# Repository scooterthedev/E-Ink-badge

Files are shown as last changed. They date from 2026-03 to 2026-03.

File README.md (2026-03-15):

# Inky - An E-Ink badge

This is an e-ink USB-C PCB badge that I'm building since I loved the Github one so much, and want to make my own! I decided that I wanted to follow a similar design route with the Github Badge so I went with the RP2040 IC.

This was my first time designing an FPC cable from scratch on a PCB! Originally, I wanted to do it to help make a board for my brother, but in the end, I found it too complicated. For this board, I decided to use Gemini to help me, since I wasn't able to find any good documentation of how to properly wire it up.

When I first started this, I though it would take at least 10 hours from when I glanced at the Github Badge, but in the end, it only took me about 4.3 hours which was insanely quick and efficient of my time!

I have attached some photos below outlining the PCB, Schematic and even the 3D rending's on the board!

## Images

3D
Schematic
PCB

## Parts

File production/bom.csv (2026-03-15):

Designator | Footprint | Quantity | Value | LCSC Part #
C1, C2 | 0402 | 2 | 0.1uF
C10, C11, C12, C5, C6, C7, C8, C9 | 0402 | 8 | 4.7µF
C13, C14 | 0402 | 2 | 12pF
C15 | 0402 | 1 | 0.1µF
C3, C4 | 0402 | 2 | 1uF
D1, D2, D3 | D_SOD-123 | 3 | MBR0530
J1 | USB_C_Receptacle_GCT_USB4105-xx-A_16P_TopMnt_Horizontal | 1 | USB_C_Receptacle_USB2.0_14P
J2 | Hirose_FH12-24S-0.5SH_1x24-1MP_P0.50mm_Horizontal | 1 | E-INK-FPC
L1 | 0805 | 1 | 10µH
Q1 | SOT-23 | 1 | BSS138
R1 | 0402 | 1 | 0.47Ω
R2, R3 | 0402 | 2 | 5.1kΩ
R4, R6 | 0402 | 2 | 10kΩ
R5 | 0402 | 1 | 1kΩ
R7, R8 | 0402 | 2 | 27Ω
SW1 | SW_SPST_PTS645Sx43SMTR92 | 1 | BOOTSEL
SW2 | SW_SPST_PTS645Sx43SMTR92 | 1 | RUN
SW3 | SW_SPST_PTS645Sx43SMTR92 | 1 | W
SW4 | SW_SPST_PTS645Sx43SMTR92 | 1 | A
SW5 | SW_SPST_PTS645Sx43SMTR92 | 1 | S
SW6 | SW_SPST_PTS645Sx43SMTR92 | 1 | D
U1 | QFN-56-1EP_7x7mm_P0.4mm_EP3.2x3.2mm | 1 | RP2040
U2 | SOT-23-5 | 1 | AP2112K-3.3
U3 | SOIC-8_5.3x5.3mm_P1.27mm | 1 | W25Q16JVSS
Y1 | Crystal_SMD_3215-2Pin_3.2x1.5mm | 1 | Crystal

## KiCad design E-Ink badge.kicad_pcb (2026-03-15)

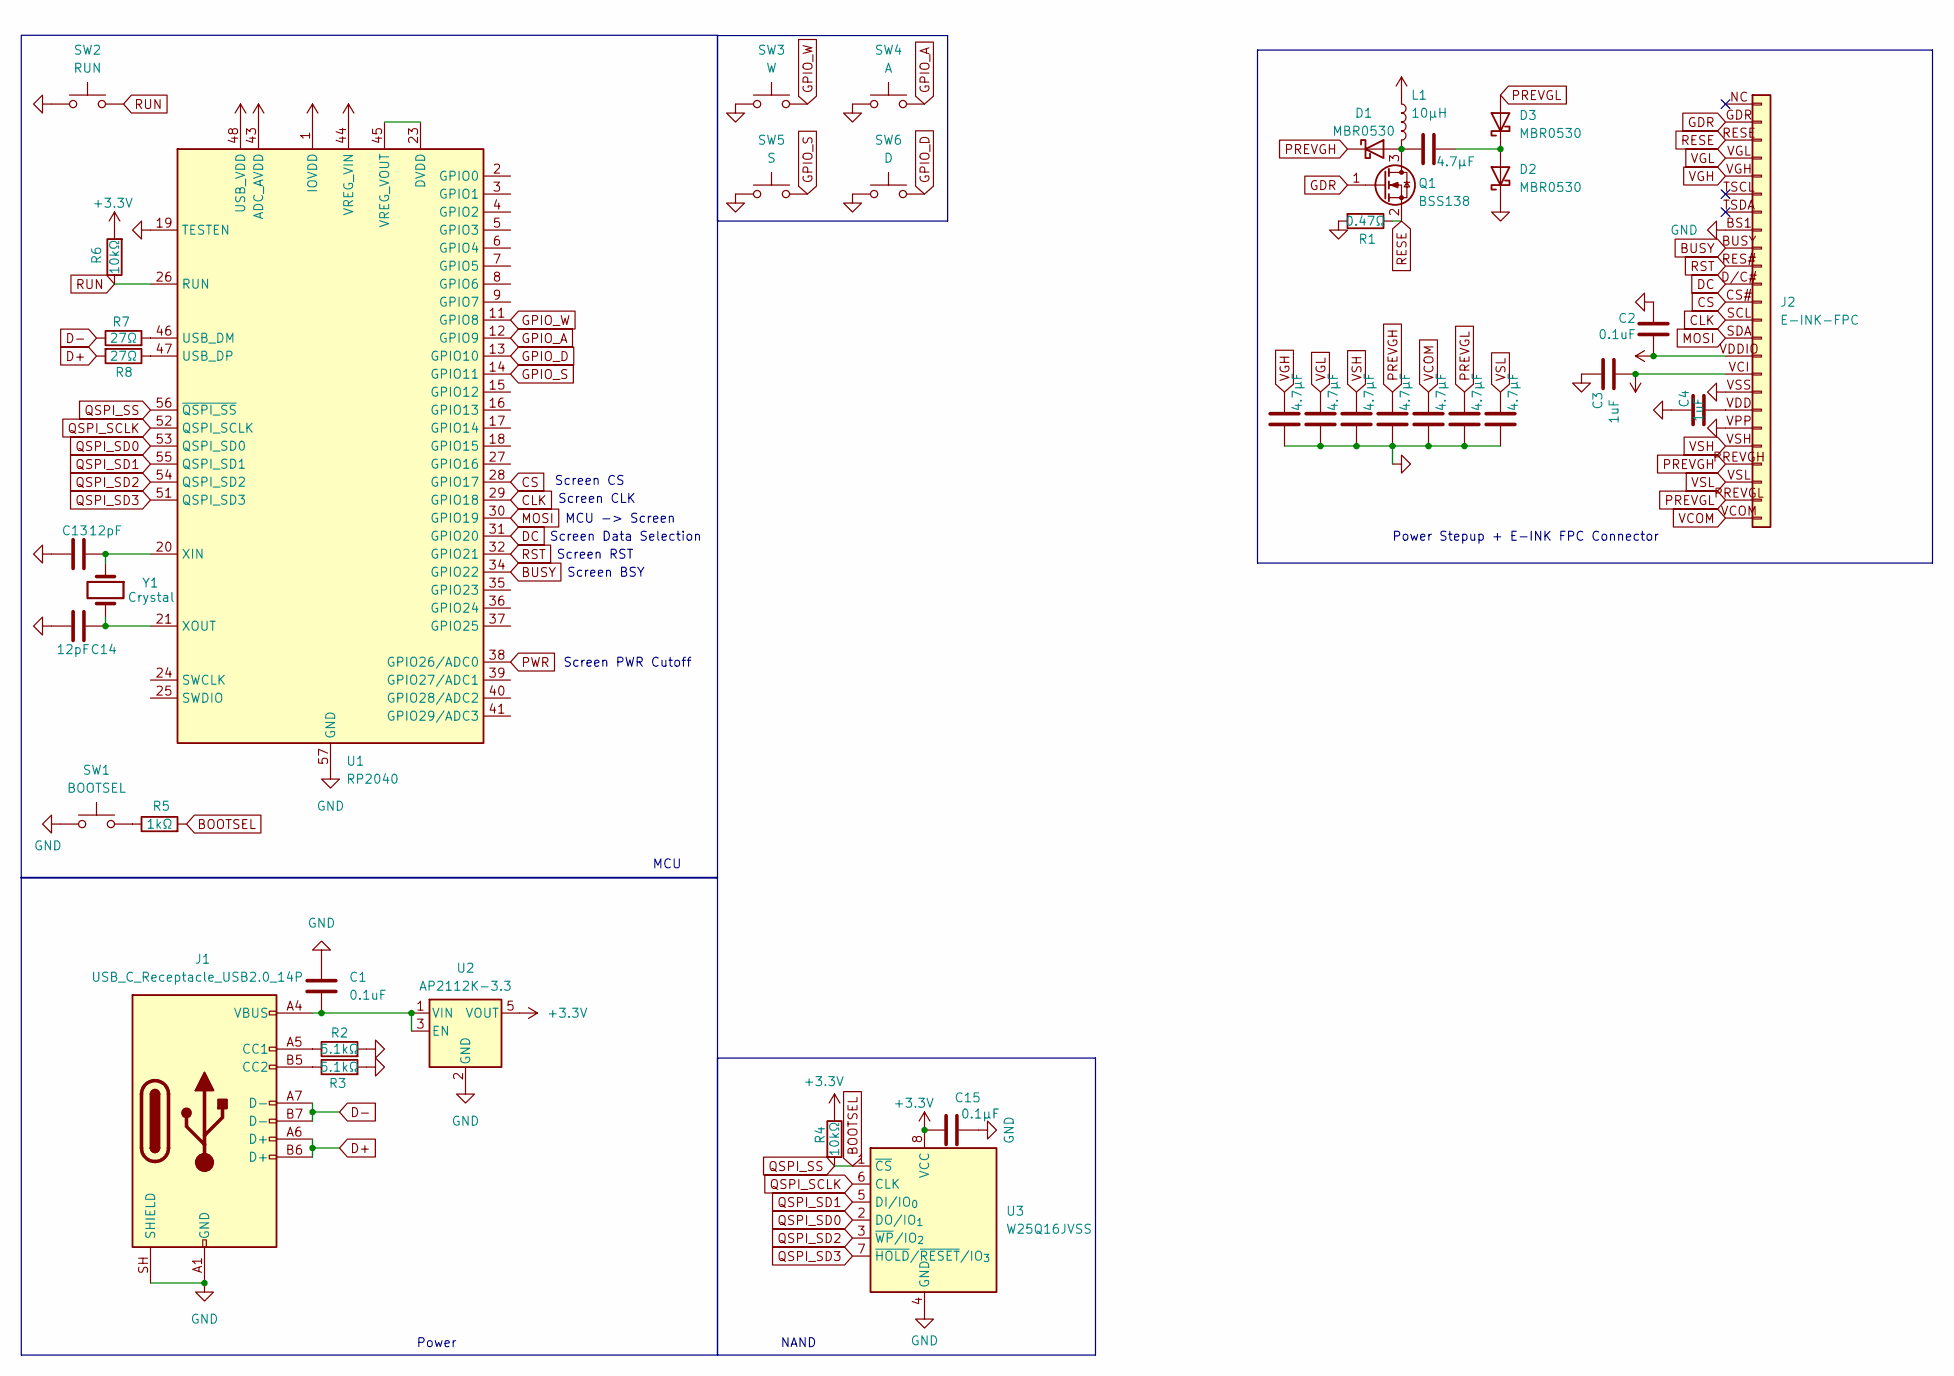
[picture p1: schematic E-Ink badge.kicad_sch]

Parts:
C1, C2: 0.1uF; C_0402_1005Metric
C3, C4: 1uF; C_0402_1005Metric
C5, C6, C7, C8, C9, C10, C11, C12: 4.7µF; C_0402_1005Metric
C13, C14: 12pF; C_0402_1005Metric
C15: 0.1µF; C_0402_1005Metric
D1, D2, D3: MBR0530; D_SOD-123
J1: USB_C_Receptacle_USB2.0_14P; USB_C_Receptacle_GCT_USB4105-xx-A_16P_TopMnt_Horizontal
J2: E-INK-FPC; Hirose_FH12-24S-0.5SH_1x24-1MP_P0.50mm_Horizontal
L1: 10µH; L_0805_2012Metric
Q1: BSS138; SOT-23
R1: 0.47Ω; C_0402_1005Metric
R2, R3: 5.1kΩ; C_0402_1005Metric
R4, R6: 10kΩ; C_0402_1005Metric
R5: 1kΩ; C_0402_1005Metric
R7, R8: 27Ω; C_0402_1005Metric
SW1: BOOTSEL; SW_SPST_PTS645Sx43SMTR92
SW2: RUN; SW_SPST_PTS645Sx43SMTR92
SW3: W; SW_SPST_PTS645Sx43SMTR92
SW4: A; SW_SPST_PTS645Sx43SMTR92
SW5: S; SW_SPST_PTS645Sx43SMTR92
SW6: D; SW_SPST_PTS645Sx43SMTR92
U1: RP2040; QFN-56-1EP_7x7mm_P0.4mm_EP3.2x3.2mm
U2: AP2112K-3.3; SOT-23-5
U3: W25Q16JVSS; SOIC-8_5.3x5.3mm_P1.27mm
Y1: Crystal; Crystal_SMD_3215-2Pin_3.2x1.5mm

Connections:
+3.3V: C2.1, C3.1, C15.1, J2.VCI (Pin_16), J2.VDDIO (Pin_15), L1.1, R4.1, R6.2, U1.1 (IOVDD), U1.10 (IOVDD), U1.22 (IOVDD), U1.33 (IOVDD), U1.42 (IOVDD), U1.43 (ADC_AVDD), U1.44 (VREG_VIN), U1.48 (USB_VDD), U1.49 (IOVDD), U2.5 (VOUT), U3.8 (VCC)
BOOTSEL: R4.2, R5.2, U1.56 (~QSPI_SS), U3.1 (~CS)
BUSY: J2.BUSY (Pin_9), U1.34 (GPIO22)
CLK: J2.SCL (Pin_13), U1.29 (GPIO18)
CS: J2.CS# (Pin_12), U1.28 (GPIO17)
D+: J1.A6 (D+), J1.B6 (D+), R8.2
D-: J1.A7 (D-), J1.B7 (D-), R7.1
DC: J2.D/C# (Pin_11), U1.31 (GPIO20)
GDR: J2.GDR (Pin_2), Q1.1 (G)
GND: C1.1, C2.2, C3.2, C4.2, C6.1, C7.1, C8.1, C9.1, C10.1, C11.1, C12.1, C13.2, C14.2, C15.2, D2.1 (K), J1.A1 (GND), J1.A12 (GND), J1.B1 (GND), J1.B12 (GND), J1.SH (SHIELD), J2.BS1 (Pin_8), J2.VPP (Pin_19), J2.VSS (Pin_17), R1.2, R2.2, R3.2, SW1.1, SW2.1, SW3.1, SW4.1, SW5.1, SW6.1, U1.19 (TESTEN), U1.57 (GND), U2.2 (GND), U3.4 (GND)
GPIO_A: SW4.2, U1.12 (GPIO9)
GPIO_D: SW6.2, U1.13 (GPIO10)
GPIO_S: SW5.2, U1.14 (GPIO11)
GPIO_W: SW3.2, U1.11 (GPIO8)
MOSI: J2.SDA (Pin_14), U1.30 (GPIO19)
unnamed: C5.1, D1.2 (A), L1.2, Q1.3 (D)
unnamed: C5.2, D2.2 (A), D3.1 (K)
unnamed: J1.A5 (CC1), R2.1
unnamed: J1.B5 (CC2), R3.1
unnamed: C4.1, J2.VDD (Pin_18)
unnamed: R5.1, SW1.2
unnamed: R7.2, U1.46 (USB_DM)
unnamed: R8.1, U1.47 (USB_DP)
unnamed: U1.23 (DVDD), U1.45 (VREG_VOUT), U1.50 (DVDD)
unnamed: C13.1, U1.20 (XIN), Y1.1
unnamed: C14.1, U1.21 (XOUT), Y1.2
unnamed: C1.2, J1.A4 (VBUS), J1.A9 (VBUS), J1.B4 (VBUS), J1.B9 (VBUS), U2.1 (VIN), U2.3 (EN)
PREVGH: C9.2, D1.1 (K), J2.PREVGH (Pin_21)
PREVGL: C11.2, D3.2 (A), J2.PREVGL (Pin_23)
PWR: U1.38 (GPIO26/ADC0)
QSPI_SCLK: U1.52 (QSPI_SCLK), U3.6 (CLK)
QSPI_SD0: U1.53 (QSPI_SD0), U3.2 (DO/IO_{1})
QSPI_SD1: U1.55 (QSPI_SD1), U3.5 (DI/IO_{0})
QSPI_SD2: U1.54 (QSPI_SD2), U3.3 (~WP/IO_{2})
QSPI_SD3: U1.51 (QSPI_SD3), U3.7 (~HOLD/~RESET/IO_{3})
RESE: J2.RESE (Pin_3), Q1.2 (S), R1.1
RST: J2.RES# (Pin_10), U1.32 (GPIO21)
RUN: R6.1, SW2.2, U1.26 (RUN)
VCOM: C10.2, J2.VCOM (Pin_24)
VGH: C6.2, J2.VGH (Pin_5)
VGL: C7.2, J2.VGL (Pin_4)
VSH: C8.2, J2.VSH (Pin_20)
VSL: C12.2, J2.VSL (Pin_22)

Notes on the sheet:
Screen CS
Screen BSY
Screen PWR Cutoff
Power
Power Stepup + E-INK FPC Connector
MCU
MCU -> Screen
Screen Data Selection
Screen RST
Screen CLK
NAND

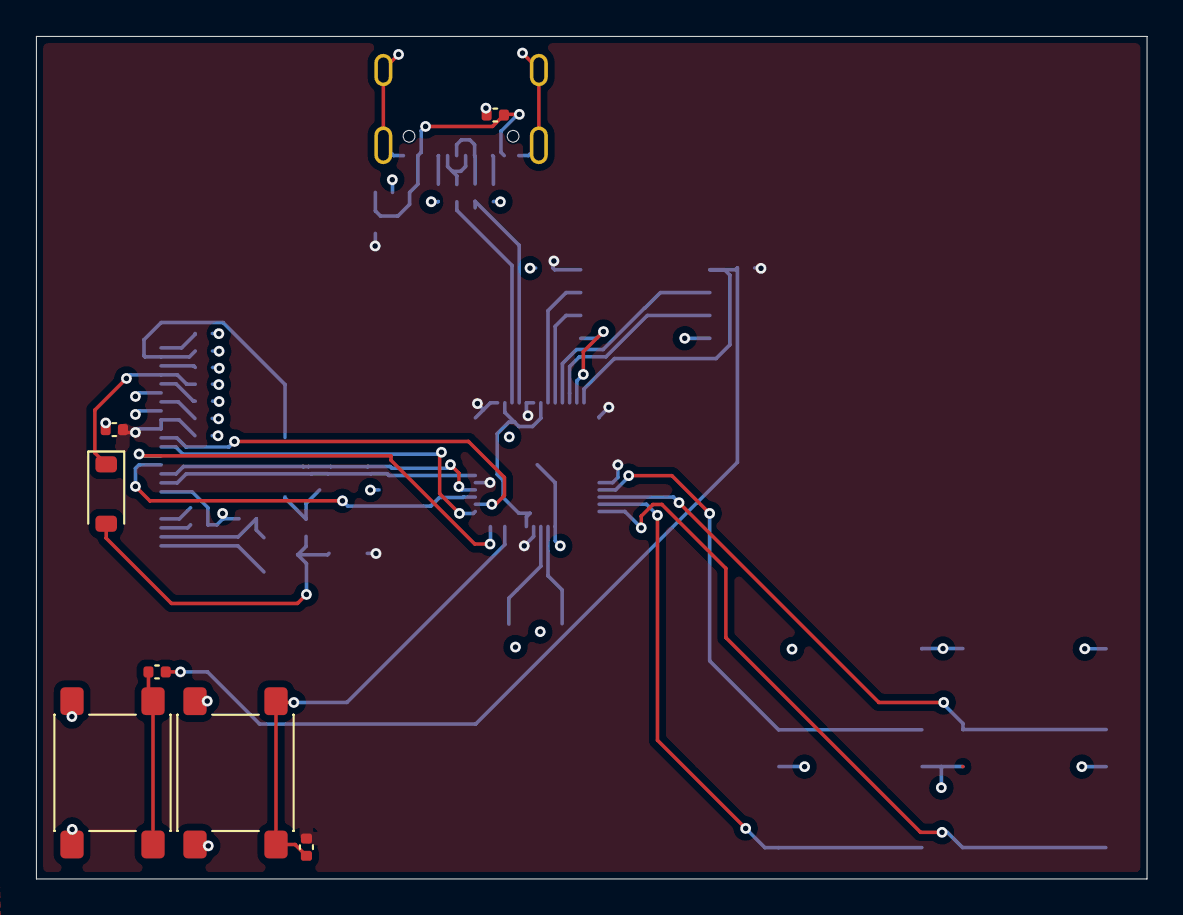
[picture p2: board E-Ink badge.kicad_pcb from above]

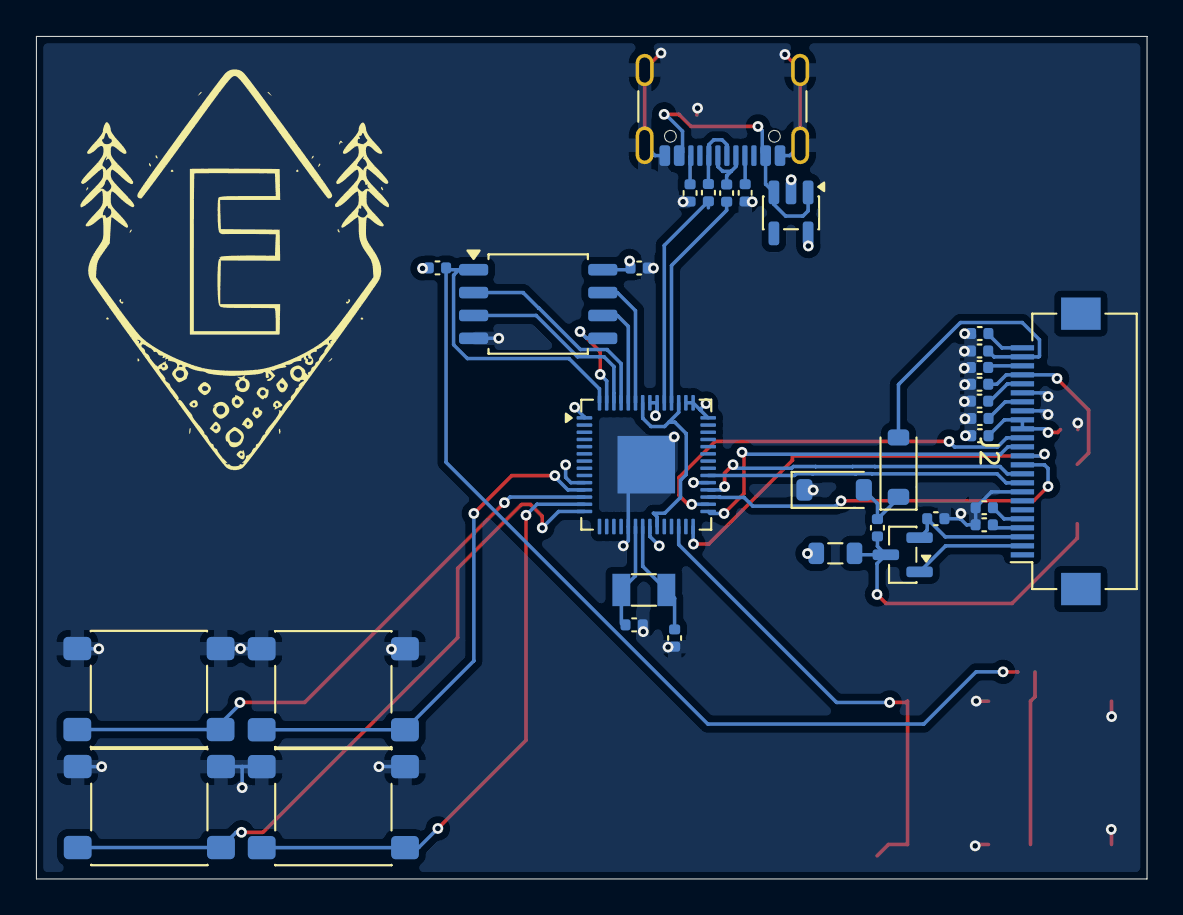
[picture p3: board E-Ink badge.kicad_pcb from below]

Board: 2 copper layers, 61.7 x 46.8 mm, 40 parts (33 on the bottom side), 42 nets.

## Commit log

2026-03-06 FPC + NAND Flash done
    [E-Ink badge.kicad_sch]
2026-03-06 BOOTSEL + RUN wired up
    [E-Ink badge.kicad_sch]
2026-03-06 Finished the main schematic besides for some pwr cutoff stuff
    [E-Ink badge.kicad_sch]
2026-03-15 Continued routing the PCB
    routed parts of the MCU, most of the FPC Cable and stuff like that.
    [E-Ink badge.kicad_pcb, E-Ink badge.kicad_sch]
2026-03-15 Finally finished routing the whole board!
    [E-Ink badge.kicad_pcb, E-Ink badge.kicad_sch]
2026-03-15 added prod files!
    [bom.csv, designators.csv, positions.csv]
2026-03-15 Finished some PCB art + updated prod files
    [E-Ink badge.kicad_pcb, positions.csv]
